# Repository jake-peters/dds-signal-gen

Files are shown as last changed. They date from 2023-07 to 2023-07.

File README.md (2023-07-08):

# DDS Signal Generator using AD9834

A signal generator designed around Analog Devices AD9834 DDS chip capable of outputting sinusoidal, triangle and square waves. Output filtering with a 9th order Elliptic filter or 7th order Linear Phase filter. PCB designed in KiCad 6.

V2 version includes update to correct orientation issue with latching relays.

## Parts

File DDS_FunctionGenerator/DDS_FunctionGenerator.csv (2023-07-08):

Source: | C:\Users\jakem\Documents\KiCad\6.0\projects\DDS_FunctionGen\DDS_FunctionGenerator\DDS_FunctionGenerator.kicad_sch
Date: | 1/28/2023 16:16
Tool: | Eeschema (6.0.6)
Generator: | D:\Programs\KiCad\6.0\bin\scripting\plugins/bom_csv_grouped_by_value.py
Component Count: | 137
Individual Components:
Item | Qty | Reference(s) | Value | LibPart | Footprint | Datasheet | Comp_Value | Part_Number
 |  | C1 | 10u | SMD_Passives:CAP_0805 | SMD_Passives_Reflow:SMD_0805 |  | 10u | GRM21BR61H106KE43L
 |  | C2 | 2u2 | SMD_Passives:CAP_0603 | SMD_Passives_Reflow:SMD_0603 |  | 2u2 | GRM188R6YA225KA12D
 |  | C3 | 10u | SMD_Passives:CAP_0805 | SMD_Passives_Reflow:SMD_0805 |  | 10u | GRM21BR61H106KE43L
 |  | C4 | 2u2 | SMD_Passives:CAP_0603 | SMD_Passives_Reflow:SMD_0603 |  | 2u2 | GRM188R6YA225KA12D
 |  | C5 | 2u2 | SMD_Passives:CAP_0603 | SMD_Passives_Reflow:SMD_0603 |  | 2u2 | GRM188R6YA225KA12D
 |  | C6 | 10u | SMD_Passives:CAP_0805 | SMD_Passives_Reflow:SMD_0805 |  | 10u | GRM21BR61H106KE43L
 |  | C7 | 2u2 | SMD_Passives:CAP_0603 | SMD_Passives_Reflow:SMD_0603 |  | 2u2 | GRM188R6YA225KA12D
 |  | C8 | 10u | SMD_Passives:CAP_0805 | SMD_Passives_Reflow:SMD_0805 |  | 10u | GRM21BR61H106KE43L
 |  | C9 | 2u2 | SMD_Passives:CAP_0603 | SMD_Passives_Reflow:SMD_0603 |  | 2u2 | GRM188R6YA225KA12D
 |  | C10 | 10u | SMD_Passives:CAP_0805 | SMD_Passives_Reflow:SMD_0805 |  | 10u | GRM21BR61H106KE43L
 |  | C11 | C11-DNI | SMD_Passives:CAP_0603 | SMD_Passives_Reflow:SMD_0603 |  | 10u | GRM21BR61H106KE43L
 |  | C12 | 100n | SMD_Passives:CAP_0603 | SMD_Passives_Reflow:SMD_0603 |  | 100n | 06035C104JAT4A
 |  | C13 | 5n6 | SMD_Passives:CAP_0603 | SMD_Passives_Reflow:SMD_0603 |  | 5n6 | 06035C562JAT2A
 |  | C14 | 2u2 | SMD_Passives:CAP_0603 | SMD_Passives_Reflow:SMD_0603 |  | 2u2 | GRM188R6YA225KA12D
 |  | C15 | C15-DNI | SMD_Passives:CAP_0603 | SMD_Passives_Reflow:SMD_0603 |  | DNI | GRM188R6YA225KA12D
 |  | C16 | 2u2 | SMD_Passives:CAP_0603 | SMD_Passives_Reflow:SMD_0603 |  | 2u2 | GRM188R6YA225KA12D
 |  | C17 | 8.6508E+11 | DDS_FunctionGenerator_Library:865080345010 | DDS_FunctionGenerator_Library:865080345010 |  | 150u | 8.6508E+11
 |  | C18 | 8.6508E+11 | DDS_FunctionGenerator_Library:865080345010 | DDS_FunctionGenerator_Library:865080345010 |  | 150u | 8.6508E+11
 |  | C19 | 2u2 | SMD_Passives:CAP_0603 | SMD_Passives_Reflow:SMD_0603 |  | 2u2 | GRM188R6YA225KA12D
 |  | C20 | 20p | SMD_Passives:CAP_0603 | SMD_Passives_Reflow:SMD_0603 |  | 20p | GCM1885C2A200FA16D
 |  | C21 | 82p | SMD_Passives:CAP_0603 | SMD_Passives_Reflow:SMD_0603 |  | 82p | GCM1885C2A820FA16D
 |  | C22 | 33p | SMD_Passives:CAP_0603 | SMD_Passives_Reflow:SMD_0603 |  | 33p | GRM1885C2A330FA01D
 |  | C23 | 82p | SMD_Passives:CAP_0603 | SMD_Passives_Reflow:SMD_0603 |  | 82p | GCM1885C2A820FA16D
 |  | C24 | 39p | SMD_Passives:CAP_0603 | SMD_Passives_Reflow:SMD_0603 |  | 39p | GRM1885C1H390FA01J
 |  | C25 | 160p | SMD_Passives:CAP_0603 | SMD_Passives_Reflow:SMD_0603 |  | 160p | GCM1885C2A161GA16J
 |  | C26 | 220p | SMD_Passives:CAP_0603 | SMD_Passives_Reflow:SMD_0603 |  | 220p | GCM1885C2A221FA16D
 |  | C27 | 240p | SMD_Passives:CAP_0603 | SMD_Passives_Reflow:SMD_0603 |  | 240p | GRM1885C1H241GA01J
 |  | C28 | 180p | SMD_Passives:CAP_0603 | SMD_Passives_Reflow:SMD_0603 |  | 180p | VJ0603A181FXACW1BC
 |  | C29 | 2u2 | SMD_Passives:CAP_0603 | SMD_Passives_Reflow:SMD_0603 |  | 2u2 | GRM188R6YA225KA12D
 |  | C30 | 62p | SMD_Passives:CAP_0603 | SMD_Passives_Reflow:SMD_0603 |  | 62p | GCM1885C2A620FA16D
 |  | C31 | 200p | SMD_Passives:CAP_0603 | SMD_Passives_Reflow:SMD_0603 |  | 200p | GCM1885C2A201FA16J
 |  | C32 | 270p | SMD_Passives:CAP_0603 | SMD_Passives_Reflow:SMD_0603 |  | 270p | GCM1885C2A271FA16D
 |  | C33 | 510p | SMD_Passives:CAP_0603 | SMD_Passives_Reflow:SMD_0603 |  | 510p | GRM1885C1H511GA01D
 |  | C34 | 10u | SMD_Passives:CAP_POL_0805 | SMD_Passives_Reflow:SMD_POL_0805 |  | 10u | TMCP1A106KTRF
 |  | C35 | 100n | SMD_Passives:CAP_0603 | SMD_Passives_Reflow:SMD_0603 |  | 100n | C0603C104J5RACTU
 |  | C36 | 100n | SMD_Passives:CAP_0603 | SMD_Passives_Reflow:SMD_0603 |  | 100n | C0603C104J5RACTU
 |  | C37 | 10u | SMD_Passives:CAP_POL_0805 | SMD_Passives_Reflow:SMD_POL_0805 |  | 10u | TMCP1A106KTRF
 |  | C38 | 500f | SMD_Passives:CAP_0402 | SMD_Passives_Reflow:SMD_0402 |  | 500f | GJM1555C1HR50WB01D
 |  | C39 | 10n | SMD_Passives:CAP_0603 | SMD_Passives_Reflow:SMD_0603 |  | 10n | C0603C103J5RACTU
 |  | C40 | 100n | SMD_Passives:CAP_0603 | SMD_Passives_Reflow:SMD_0603 |  | 100n | C0603C104J5RACTU
 |  | C41 | 100n | SMD_Passives:CAP_0603 | SMD_Passives_Reflow:SMD_0603 |  | 100n | C0603C104J5RACTU
 |  | C42 | 100n | SMD_Passives:CAP_0603 | SMD_Passives_Reflow:SMD_0603 |  | 100n | C0603C104J5RACTU
 |  | C43 | C43-DNI | SMD_Passives:CAP_0603 | SMD_Passives_Reflow:SMD_0603 |  | DNI | GRM1885C1H200GA01J
 |  | C44 | C44-DNI | SMD_Passives:CAP_0603 | SMD_Passives_Reflow:SMD_0603 |  | DNI | GRM1885C1H200GA01J
 |  | C45 | 100n | SMD_Passives:CAP_0603 | SMD_Passives_Reflow:SMD_0603 |  | 100n | C0603C104J5RACTU
 |  | C46 | C46-DNI | SMD_Passives:CAP_0402 | SMD_Passives_Reflow:SMD_0402 |  | DNI | GJM1555C1HR50WB01D
 |  | C47 | 2u2 | SMD_Passives:CAP_0603 | SMD_Passives_Reflow:SMD_0603 |  | 2u2 | GRM188R6YA225KA12D
 |  | C48 | 2u2 | SMD_Passives:CAP_0603 | SMD_Passives_Reflow:SMD_0603 |  | 2u2 | GRM188R6YA225KA12D
 |  | C49 | 2u2 | SMD_Passives:CAP_0603 | SMD_Passives_Reflow:SMD_0603 |  | 2u2 | GRM188R6YA225KA12D
 |  | C50 | 2u2 | SMD_Passives:CAP_0603 | SMD_Passives_Reflow:SMD_0603 |  | 2u2 | GRM188R6YA225KA12D
 |  | D1 | 1N4148W-E3-18 | DDS_FunctionGenerator_Library:1N4148W-E3-18 | DDS_FunctionGenerator_Library:SOD-123 |  |  | 1N4148W-E3-18
 |  | D2 | 1N4148W-E3-18 | DDS_FunctionGenerator_Library:1N4148W-E3-18 | DDS_FunctionGenerator_Library:SOD-123 |  |  | 1N4148W-E3-18
 |  | FB1 | 470R @ 100 MHz | SMD_Passives:BEAD_0603 | SMD_Passives_Reflow:SMD_0603 |  | 470R @ 100MHz | MMZ1608B471CTAH0
 |  | H1 | 0.152_IN_DIA | Mounting_Holes:0.152_IN_DIA | Mounting_Holes:0.152_IN_DIA-6-32 |  |  | 4817
 |  | H2 | 0.152_IN_DIA | Mounting_Holes:0.152_IN_DIA | Mounting_Holes:0.152_IN_DIA-6-32 |  |  | 4817
 |  | H3 | 0.152_IN_DIA | Mounting_Holes:0.152_IN_DIA | Mounting_Holes:0.152_IN_DIA-6-32 |  |  | 4817
 |  | H4 | 0.152_IN_DIA | Mounting_Holes:0.152_IN_DIA | Mounting_Holes:0.152_IN_DIA-6-32 |  |  | 4817
 |  | J1 | 6.91411E+11 | DDS_FunctionGenerator_Library:691411410002 | DDS_FunctionGenerator_Library:691411410002 |  |  | 6.91411E+11
 |  | J2 | SMA_CONN_TH | Connectors_Coax:SMA_CONN_TH | Connectors_Coax:SMA_CONN_TH |  |  | 901-144-8RFX
 |  | J3 | SMA_CONN_TH | Connectors_Coax:SMA_CONN_TH | Connectors_Coax:SMA_CONN_TH |  |  | 901-144-8RFX
 |  | J4 | HEADER_01X10 | Connectors_Header:HEADER_01X10 | Connector_PinSocket_2.54mm:PinSocket_1x10_P2.54mm_Vertical |  |  | 61301011821
 |  | J5 | SMA_CONN_TH | Connectors_Coax:SMA_CONN_TH | Connectors_Coax:SMA_CONN_TH |  |  | 901-144-8RFX
 |  | K1 | DS1E-SL-DC5V | DDS_FunctionGenerator_Library:DS1E-SL-DC5V | DDS_FunctionGenerator_Library:DS1E-SL-DC5V |  |  | DS1E-SL-DC5V
 |  | K2 | DS1E-SL-DC5V | :DS1E-SL-DC5V_1 | DDS_FunctionGenerator_Library:DS1E-SL-DC5V |  |  | DS1E-SL-DC5V
 |  | L1 | 33u | DDS_FunctionGenerator_Library:7447715330 | DDS_FunctionGenerator_Library:7447715330 |  | 33u | 7447715330
 |  | L2 | 330n | SMD_Passives:IND_1008 | SMD_Passives_Reflow:SMD_1008 |  | 330n | LQW2UASR33F00L
 |  | L3 | 390n | SMD_Passives:IND_1008 | SMD_Passives_Reflow:SMD_1008 |  | 390n | LQW2UASR39F00L
 |  | L4 | 620n | SMD_Passives:IND_1008 | SMD_Passives_Reflow:SMD_1008 |  | 620n | LQW2UASR62F0CL
 |  | L5 | 470n | SMD_Passives:IND_1008 | SMD_Passives_Reflow:SMD_1008 |  | 470n | LQW2UASR47F0CL
 |  | L6 | 390n | SMD_Passives:IND_1008 | SMD_Passives_Reflow:SMD_1008 |  | 390n | LQW2UASR39F00L
 |  | L7 | 580n | SMD_Passives:IND_0603 | SMD_Passives_Reflow:SMD_0603 |  | 580n | LQW18CAR58J00D
 |  | L8 | 820n | SMD_Passives:IND_1008 | SMD_Passives_Reflow:SMD_1008 |  | 820n | LQW2UASR82F00L
 |  | POT1 | PTN10-E200HB20 | DDS_FunctionGenerator_Library:PTN10-E200HB20 | DDS_FunctionGenerator_Library:PTN10-E200HB20 |  | 200k | PTN10-E200HB20
 |  | Q1 | BFR182W | DDS_FunctionGenerator_Library:BFR182W | DDS_FunctionGenerator_Library:SOT323_BFR182W |  |  | BFR182W
 |  | Q2 | BFR182W | DDS_FunctionGenerator_Library:BFR182W | DDS_FunctionGenerator_Library:SOT323_BFR182W |  |  | BFR182W
 |  | R1 | 100k | SMD_Passives:RES_0603 | SMD_Passives_Reflow:SMD_0603 |  | 100k | RT0603DRE10100KL
 |  | R2 | 100k | SMD_Passives:RES_0603 | SMD_Passives_Reflow:SMD_0603 |  | 100k | RT0603DRE10100KL
 |  | R3 | 28k7 | SMD_Passives:RES_0603 | SMD_Passives_Reflow:SMD_0603 |  | 28k7 | RT0603DRE0728K7L
 |  | R4 | 3M32 | SMD_Passives:RES_0603 | SMD_Passives_Reflow:SMD_0603 |  | 3M32 | RC0603FR-073M32L
 |  | R5 | 1M | SMD_Passives:RES_0603 | SMD_Passives_Reflow:SMD_0603 |  | 1M | RC0603FR-101ML
 |  | R6 | 53k6 | SMD_Passives:RES_0603 | SMD_Passives_Reflow:SMD_0603 |  | 53k6 | RT0603DRE0753K6L
 |  | R7 | 10k | SMD_Passives:RES_0603 | SMD_Passives_Reflow:SMD_0603 |  | 10k | RT0603FRE1310KL
 |  | R8 | 7k87 | SMD_Passives:RES_0603 | SMD_Passives_Reflow:SMD_0603 |  | 7k87 | RT0603DRE077K87L
 |  | R9 | 9k76 | SMD_Passives:RES_0603 | SMD_Passives_Reflow:SMD_0603 |  | 9k76 | RT0603DRE079K76L
 |  | R10 | 499R | SMD_Passives:RES_0603 | SMD_Passives_Reflow:SMD_0603 |  | 499R | RT0603DRD07499RL
 |  | R11 | 499R | SMD_Passives:RES_0603 | SMD_Passives_Reflow:SMD_0603 |  | 499R | RT0603DRD07499RL
 |  | R12 | 249R | SMD_Passives:RES_0603 | SMD_Passives_Reflow:SMD_0603 |  | 249R | RT0603BRD07249RL
 |  | R13 | 100R | SMD_Passives:RES_0603 | SMD_Passives_Reflow:SMD_0603 |  | 100R | CRCW0603100RFKEAHP
 |  | R14 | 100R | SMD_Passives:RES_0603 | SMD_Passives_Reflow:SMD_0603 |  | 100R | CRCW0603100RFKEAHP
 |  | R15 | 249R | SMD_Passives:RES_0603 | SMD_Passives_Reflow:SMD_0603 |  | 249R | RT0603BRD07249RL
 |  | R16 | 1k78 | SMD_Passives:RES_0603 | SMD_Passives_Reflow:SMD_0603 |  | 1k78 | RT0603DRD071K78L
 |  | R17 | 6k8 | SMD_Passives:RES_0603 | SMD_Passives_Reflow:SMD_0603 |  | 6k8 | RT0603DRE076K8L
 |  | R18 | 499R | SMD_Passives:RES_0603 | SMD_Passives_Reflow:SMD_0603 |  | 499R | RT0603DRE07499RL
 |  | R19 | 1k5 | SMD_Passives:RES_0603 | SMD_Passives_Reflow:SMD_0603 |  | 1k5 | RT0603DRE071K5L
 |  | R20 | 49R9 | SMD_Passives:RES_0603 | SMD_Passives_Reflow:SMD_0603 |  | 49R9 | RT0603DRE0749R9L
 |  | R21 | 200R | SMD_Passives:RES_0603 | SMD_Passives_Reflow:SMD_0603 |  | 200R | RT0603DRE07200RL
 |  | R22 | 200R | SMD_Passives:RES_0603 | SMD_Passives_Reflow:SMD_0603 |  | 200R | RT0603DRE07200RL
 |  | R23 | 0R | SMD_Passives:RES_0603 | SMD_Passives_Reflow:SMD_0603 |  | 0R | RC0603FR-070RL
 |  | R24 | 499R | SMD_Passives:RES_0603 | SMD_Passives_Reflow:SMD_0603 |  | 499R | RT0603DRE07499RL
 |  | R25 | 1k78 | SMD_Passives:RES_0603 | SMD_Passives_Reflow:SMD_0603 |  | 1k78 | RT0603DRD071K78L
 |  | R26 | 1k5 | SMD_Passives:RES_0603 | SMD_Passives_Reflow:SMD_0603 |  | 1k5 | RT0603DRE071K5L
 |  | TP1 | TestPoint_1.5mm_PAD | Connector:TestPoint | TestPoint:TestPoint_Pad_D1.5mm | ~ |  | N/A
 |  | TP2 | TestPoint_1.5mm_PAD | Connector:TestPoint | TestPoint:TestPoint_Pad_D1.5mm | ~ |  | N/A
 |  | TP3 | TestPoint_1.5mm_PAD | Connector:TestPoint | TestPoint:TestPoint_Pad_D1.5mm | ~ |  | N/A
 |  | TP4 | TestPoint_1.5mm_PAD | Connector:TestPoint | TestPoint:TestPoint_Pad_D1.5mm | ~ |  | N/A
 |  | TP5 | TestPoint_1.5mm_PAD | Connector:TestPoint | TestPoint:TestPoint_Pad_D1.5mm | ~ |  | N/A
 |  | TP6 | TestPoint_1.5mm_PAD | Connector:TestPoint | TestPoint:TestPoint_Pad_D1.5mm | ~ |  | N/A
 |  | TP7 | TestPoint_0.8mm_PAD | Connector:TestPoint | TestPoint:TestPoint_Pad_D0.8mm | ~ |  | N/A
 |  | TP8 | TestPoint_0.8mm_PAD | Connector:TestPoint | TestPoint:TestPoint_Pad_D0.8mm | ~ |  | N/A
 |  | TP9 | TestPoint_0.8mm_PAD | Connector:TestPoint | TestPoint:TestPoint_Pad_D0.8mm | ~ |  | N/A
 |  | TP11 | TestPoint_0.8mm_PAD | Connector:TestPoint | TestPoint:TestPoint_Pad_D0.8mm | ~ |  | N/A
 |  | TP12 | TestPoint_0.8mm_PAD | Connector:TestPoint | TestPoint:TestPoint_Pad_D0.8mm | ~ |  | N/A
 |  | TP13 | TestPoint_0.8mm_PAD | Connector:TestPoint | TestPoint:TestPoint_Pad_D0.8mm | ~ |  | N/A
 |  | TP14 | TestPoint_0.8mm_PAD | Connector:TestPoint | TestPoint:TestPoint_Pad_D0.8mm | ~ |  | N/A
 |  | TP15 | TestPoint_0.8mm_PAD | Connector:TestPoint | TestPoint:TestPoint_Pad_D0.8mm | ~ |  | N/A
 |  | TP16 | TestPoint_0.8mm_PAD | Connector:TestPoint | TestPoint:TestPoint_Pad_D0.8mm | ~ |  | N/A
 |  | TP17 | TestPoint_0.8mm_PAD | Connector:TestPoint | TestPoint:TestPoint_Pad_D0.8mm | ~ |  | N/A
 |  | TP18 | TestPoint_0.8mm_PAD | Connector:TestPoint | TestPoint:TestPoint_Pad_D0.8mm | ~ |  | N/A
 |  | TP20 | TestPoint_0.8mm_PAD | Connector:TestPoint | TestPoint:TestPoint_Pad_D0.8mm | ~ |  | N/A
 |  | TP21 | TestPoint_0.8mm_PAD | Connector:TestPoint | TestPoint:TestPoint_Pad_D0.8mm | ~ |  | N/A
 |  | TP22 | TestPoint_0.8mm_PAD | Connector:TestPoint | TestPoint:TestPoint_Pad_D0.8mm | ~ |  | N/A
 |  | TP23 | TestPoint_0.8mm_PAD | Connector:TestPoint | TestPoint:TestPoint_Pad_D0.8mm | ~ |  | N/A
 |  | TP24 | TestPoint_0.8mm_PAD | Connector:TestPoint | TestPoint:TestPoint_Pad_D0.8mm | ~ |  | N/A
 |  | TP25 | TestPoint_0.8mm_PAD | Connector:TestPoint | TestPoint:TestPoint_Pad_D0.8mm | ~ |  | N/A
 |  | TP26 | TestPoint_0.8mm_PAD | Connector:TestPoint | TestPoint:TestPoint_Pad_D0.8mm | ~ |  | N/A
 |  | TP27 | TestPoint_0.8mm_PAD | Connector:TestPoint | TestPoint:TestPoint_Pad_D0.8mm | ~ |  | N/A
 |  | TP28 | TestPoint_0.8mm_PAD | Connector:TestPoint | TestPoint:TestPoint_Pad_D0.8mm | ~ |  | N/A
 |  | TP29 | TestPoint_0.8mm_PAD | Connector:TestPoint | TestPoint:TestPoint_Pad_D0.8mm | ~ |  | N/A
 |  | U1 | ADP151AUJZ | DDS_FunctionGenerator_Library:ADP151AUJZ | DDS_FunctionGenerator_Library:TSOT_5Pin |  |  | ADP151AUJZ-3.3-R7
 |  | U2 | ADP7102 | DDS_FunctionGenerator_Library:ADP7102 | DDS_FunctionGenerator_Library:LFCSP_WD_8Pin |  |  | ADP7102ACPZ-5.0-R7
 |  | U3 | ADP7182AUJZ | DDS_FunctionGenerator_Library:ADP7182AUJZ | DDS_FunctionGenerator_Library:TSOT_5Pin |  |  | ADP7182AUJZ-5.0-R7
 |  | U4 | MAX17580ATC+ | DDS_FunctionGenerator_Library:MAX17580ATC+ | DDS_FunctionGenerator_Library:TDFN-EP_12Pin |  |  | MAX17580ATC+
 |  | U5 | MCP14A0602-E/SN | DDS_FunctionGenerator_Library:MCP14A0602-E{slash}SN | DDS_FunctionGenerator_Library:SOIC_8Pin |  |  | MCP14A0602-E/SN
 |  | U6 | LT1815IS5 | DDS_FunctionGenerator_Library:LT1815IS5 | DDS_FunctionGenerator_Library:TSOT-23_S5-Package |  |  | LT1815IS5
 |  | U7 | AD9834 | Interface:AD9834 | Package_SO:TSSOP-20_4.4x6.5mm_P0.65mm | https://www.analog.com/static/imported-files/data_sheets/AD9834.pdf |  | AD9834
 |  | U8 | LT1818IS8 | DDS_FunctionGenerator_Library:LT1818IS8 | DDS_FunctionGenerator_Library:S8_Package_LT1818 |  |  | LT1818IS8
 |  | X1 | ECS-TXO-2520MV-500-AY-TR | Oscillator:ECS-2520MV-xxx-xx | Oscillator:Oscillator_SMD_ECS_2520MV-xxx-xx-4Pin_2.5x2.0mm | https://www.ecsxtal.com/store/pdf/ECS-2520MV.pdf |  | ECS-TXO-2520MV-500-AY-TR
Collated Components:
Item | Qty | Reference(s) | Value | LibPart | Footprint | Datasheet | Comp_Value | Part_Number
1 | 5 | C1, C3, C6, C8, C10 | 10u | SMD_Passives:CAP_0805 | SMD_Passives_Reflow:SMD_0805 |  | 10u | GRM21BR61H106KE43L
2 | 13 | C2, C4, C5, C7, C9, C14, C16, C19, C29, C47, C48, C49, C50 | 2u2 | SMD_Passives:CAP_0603 | SMD_Passives_Reflow:SMD_0603 |  | 2u2 | GRM188R6YA225KA12D
3 | 1 | C11 | C11-DNI | SMD_Passives:CAP_0603 | SMD_Passives_Reflow:SMD_0603 |  | 10u | GRM21BR61H106KE43L
4 | 7 | C12, C35, C36, C40, C41, C42, C45 | 100n | SMD_Passives:CAP_0603 | SMD_Passives_Reflow:SMD_0603 |  | 100n | 06035C104JAT4A
5 | 1 | C13 | 5n6 | SMD_Passives:CAP_0603 | SMD_Passives_Reflow:SMD_0603 |  | 5n6 | 06035C562JAT2A
6 | 1 | C15 | C15-DNI | SMD_Passives:CAP_0603 | SMD_Passives_Reflow:SMD_0603 |  | DNI | GRM188R6YA225KA12D
7 | 2 | C17, C18 | 8.6508E+11 | DDS_FunctionGenerator_Library:865080345010 | DDS_FunctionGenerator_Library:865080345010 |  | 150u | 865080345010
8 | 1 | C20 | 20p | SMD_Passives:CAP_0603 | SMD_Passives_Reflow:SMD_0603 |  | 20p | GCM1885C2A200FA16D
9 | 2 | C21, C23 | 82p | SMD_Passives:CAP_0603 | SMD_Passives_Reflow:SMD_0603 |  | 82p | GCM1885C2A820FA16D
10 | 1 | C22 | 33p | SMD_Passives:CAP_0603 | SMD_Passives_Reflow:SMD_0603 |  | 33p | GRM1885C2A330FA01D
11 | 1 | C24 | 39p | SMD_Passives:CAP_0603 | SMD_Passives_Reflow:SMD_0603 |  | 39p | GRM1885C1H390FA01J
12 | 1 | C25 | 160p | SMD_Passives:CAP_0603 | SMD_Passives_Reflow:SMD_0603 |  | 160p | GCM1885C2A161GA16J
13 | 1 | C26 | 220p | SMD_Passives:CAP_0603 | SMD_Passives_Reflow:SMD_0603 |  | 220p | GCM1885C2A221FA16D
14 | 1 | C27 | 240p | SMD_Passives:CAP_0603 | SMD_Passives_Reflow:SMD_0603 |  | 240p | GRM1885C1H241GA01J
15 | 1 | C28 | 180p | SMD_Passives:CAP_0603 | SMD_Passives_Reflow:SMD_0603 |  | 180p | VJ0603A181FXACW1BC
16 | 1 | C30 | 62p | SMD_Passives:CAP_0603 | SMD_Passives_Reflow:SMD_0603 |  | 62p | GCM1885C2A620FA16D
17 | 1 | C31 | 200p | SMD_Passives:CAP_0603 | SMD_Passives_Reflow:SMD_0603 |  | 200p | GCM1885C2A201FA16J
18 | 1 | C32 | 270p | SMD_Passives:CAP_0603 | SMD_Passives_Reflow:SMD_0603 |  | 270p | GCM1885C2A271FA16D
19 | 1 | C33 | 510p | SMD_Passives:CAP_0603 | SMD_Passives_Reflow:SMD_0603 |  | 510p | GRM1885C1H511GA01D
20 | 2 | C34, C37 | 10u | SMD_Passives:CAP_POL_0805 | SMD_Passives_Reflow:SMD_POL_0805 |  | 10u | TMCP1A106KTRF
21 | 1 | C38 | 500f | SMD_Passives:CAP_0402 | SMD_Passives_Reflow:SMD_0402 |  | 500f | GJM1555C1HR50WB01D
22 | 1 | C39 | 10n | SMD_Passives:CAP_0603 | SMD_Passives_Reflow:SMD_0603 |  | 10n | C0603C103J5RACTU
23 | 1 | C43 | C43-DNI | SMD_Passives:CAP_0603 | SMD_Passives_Reflow:SMD_0603 |  | DNI | GRM1885C1H200GA01J
24 | 1 | C44 | C44-DNI | SMD_Passives:CAP_0603 | SMD_Passives_Reflow:SMD_0603 |  | DNI | GRM1885C1H200GA01J
25 | 1 | C46 | C46-DNI | SMD_Passives:CAP_0402 | SMD_Passives_Reflow:SMD_0402 |  | DNI | GJM1555C1HR50WB01D
26 | 2 | D1, D2 | 1N4148W-E3-18 | DDS_FunctionGenerator_Library:1N4148W-E3-18 | DDS_FunctionGenerator_Library:SOD-123 |  |  | 1N4148W-E3-18
27 | 1 | FB1 | 470R @ 100 MHz | SMD_Passives:BEAD_0603 | SMD_Passives_Reflow:SMD_0603 |  | 470R @ 100MHz | MMZ1608B471CTAH0
28 | 4 | H1, H2, H3, H4 | 0.152_IN_DIA | Mounting_Holes:0.152_IN_DIA | Mounting_Holes:0.152_IN_DIA-6-32 |  |  | 4817
29 | 1 | J1 | 6.91411E+11 | DDS_FunctionGenerator_Library:691411410002 | DDS_FunctionGenerator_Library:691411410002 |  |  | 691411410002
30 | 3 | J2, J3, J5 | SMA_CONN_TH | Connectors_Coax:SMA_CONN_TH | Connectors_Coax:SMA_CONN_TH |  |  | 901-144-8RFX
31 | 1 | J4 | HEADER_01X10 | Connectors_Header:HEADER_01X10 | Connector_PinSocket_2.54mm:PinSocket_1x10_P2.54mm_Vertical |  |  | 61301011821
32 | 1 | K1 | DS1E-SL-DC5V | DDS_FunctionGenerator_Library:DS1E-SL-DC5V | DDS_FunctionGenerator_Library:DS1E-SL-DC5V |  |  | DS1E-SL-DC5V
33 | 1 | K2 | DS1E-SL-DC5V | :DS1E-SL-DC5V_1 | DDS_FunctionGenerator_Library:DS1E-SL-DC5V |  |  | DS1E-SL-DC5V
34 | 1 | L1 | 33u | DDS_FunctionGenerator_Library:7447715330 | DDS_FunctionGenerator_Library:7447715330 |  | 33u | 7447715330
35 | 1 | L2 | 330n | SMD_Passives:IND_1008 | SMD_Passives_Reflow:SMD_1008 |  | 330n | LQW2UASR33F00L
36 | 2 | L3, L6 | 390n | SMD_Passives:IND_1008 | SMD_Passives_Reflow:SMD_1008 |  | 390n | LQW2UASR39F00L
37 | 1 | L4 | 620n | SMD_Passives:IND_1008 | SMD_Passives_Reflow:SMD_1008 |  | 620n | LQW2UASR62F0CL
38 | 1 | L5 | 470n | SMD_Passives:IND_1008 | SMD_Passives_Reflow:SMD_1008 |  | 470n | LQW2UASR47F0CL
39 | 1 | L7 | 580n | SMD_Passives:IND_0603 | SMD_Passives_Reflow:SMD_0603 |  | 580n | LQW18CAR58J00D
40 | 1 | L8 | 820n | SMD_Passives:IND_1008 | SMD_Passives_Reflow:SMD_1008 |  | 820n | LQW2UASR82F00L
41 | 1 | POT1 | PTN10-E200HB20 | DDS_FunctionGenerator_Library:PTN10-E200HB20 | DDS_FunctionGenerator_Library:PTN10-E200HB20 |  | 200k | PTN10-E200HB20
42 | 2 | Q1, Q2 | BFR182W | DDS_FunctionGenerator_Library:BFR182W | DDS_FunctionGenerator_Library:SOT323_BFR182W |  |  | BFR182W
43 | 2 | R1, R2 | 100k | SMD_Passives:RES_0603 | SMD_Passives_Reflow:SMD_0603 |  | 100k | RT0603DRE10100KL
44 | 1 | R3 | 28k7 | SMD_Passives:RES_0603 | SMD_Passives_Reflow:SMD_0603 |  | 28k7 | RT0603DRE0728K7L
45 | 1 | R4 | 3M32 | SMD_Passives:RES_0603 | SMD_Passives_Reflow:SMD_0603 |  | 3M32 | RC0603FR-073M32L
46 | 1 | R5 | 1M | SMD_Passives:RES_0603 | SMD_Passives_Reflow:SMD_0603 |  | 1M | RC0603FR-101ML
47 | 1 | R6 | 53k6 | SMD_Passives:RES_0603 | SMD_Passives_Reflow:SMD_0603 |  | 53k6 | RT0603DRE0753K6L
48 | 1 | R7 | 10k | SMD_Passives:RES_0603 | SMD_Passives_Reflow:SMD_0603 |  | 10k | RT0603FRE1310KL
49 | 1 | R8 | 7k87 | SMD_Passives:RES_0603 | SMD_Passives_Reflow:SMD_0603 |  | 7k87 | RT0603DRE077K87L
50 | 1 | R9 | 9k76 | SMD_Passives:RES_0603 | SMD_Passives_Reflow:SMD_0603 |  | 9k76 | RT0603DRE079K76L
51 | 4 | R10, R11, R18, R24 | 499R | SMD_Passives:RES_0603 | SMD_Passives_Reflow:SMD_0603 |  | 499R | RT0603DRD07499RL
52 | 2 | R12, R15 | 249R | SMD_Passives:RES_0603 | SMD_Passives_Reflow:SMD_0603 |  | 249R | RT0603BRD07249RL
53 | 2 | R13, R14 | 100R | SMD_Passives:RES_0603 | SMD_Passives_Reflow:SMD_0603 |  | 100R | CRCW0603100RFKEAHP
54 | 2 | R16, R25 | 1k78 | SMD_Passives:RES_0603 | SMD_Passives_Reflow:SMD_0603 |  | 1k78 | RT0603DRD071K78L
55 | 1 | R17 | 6k8 | SMD_Passives:RES_0603 | SMD_Passives_Reflow:SMD_0603 |  | 6k8 | RT0603DRE076K8L
56 | 2 | R19, R26 | 1k5 | SMD_Passives:RES_0603 | SMD_Passives_Reflow:SMD_0603 |  | 1k5 | RT0603DRE071K5L
57 | 1 | R20 | 49R9 | SMD_Passives:RES_0603 | SMD_Passives_Reflow:SMD_0603 |  | 49R9 | RT0603DRE0749R9L
58 | 2 | R21, R22 | 200R | SMD_Passives:RES_0603 | SMD_Passives_Reflow:SMD_0603 |  | 200R | RT0603DRE07200RL
59 | 1 | R23 | 0R | SMD_Passives:RES_0603 | SMD_Passives_Reflow:SMD_0603 |  | 0R | RC0603FR-070RL
60 | 6 | TP1, TP2, TP3, TP4, TP5, TP6 | TestPoint_1.5mm_PAD | Connector:TestPoint | TestPoint:TestPoint_Pad_D1.5mm | ~ |  | N/A
61 | 21 | TP7, TP8, TP9, TP11, TP12, TP13, TP14, TP15, TP16, TP17, TP18, TP20, TP21, TP22, TP23, TP24, TP25, TP26, TP27, TP28, TP29 | TestPoint_0.8mm_PAD | Connector:TestPoint | TestPoint:TestPoint_Pad_D0.8mm | ~ |  | N/A
62 | 1 | U1 | ADP151AUJZ | DDS_FunctionGenerator_Library:ADP151AUJZ | DDS_FunctionGenerator_Library:TSOT_5Pin |  |  | ADP151AUJZ-3.3-R7
63 | 1 | U2 | ADP7102 | DDS_FunctionGenerator_Library:ADP7102 | DDS_FunctionGenerator_Library:LFCSP_WD_8Pin |  |  | ADP7102ACPZ-5.0-R7
64 | 1 | U3 | ADP7182AUJZ | DDS_FunctionGenerator_Library:ADP7182AUJZ | DDS_FunctionGenerator_Library:TSOT_5Pin |  |  | ADP7182AUJZ-5.0-R7
65 | 1 | U4 | MAX17580ATC+ | DDS_FunctionGenerator_Library:MAX17580ATC+ | DDS_FunctionGenerator_Library:TDFN-EP_12Pin |  |  | MAX17580ATC+
66 | 1 | U5 | MCP14A0602-E/SN | DDS_FunctionGenerator_Library:MCP14A0602-E{slash}SN | DDS_FunctionGenerator_Library:SOIC_8Pin |  |  | MCP14A0602-E/SN
67 | 1 | U6 | LT1815IS5 | DDS_FunctionGenerator_Library:LT1815IS5 | DDS_FunctionGenerator_Library:TSOT-23_S5-Package |  |  | LT1815IS5
68 | 1 | U7 | AD9834 | Interface:AD9834 | Package_SO:TSSOP-20_4.4x6.5mm_P0.65mm | https://www.analog.com/static/imported-files/data_sheets/AD9834.pdf |  | AD9834
69 | 1 | U8 | LT1818IS8 | DDS_FunctionGenerator_Library:LT1818IS8 | DDS_FunctionGenerator_Library:S8_Package_LT1818 |  |  | LT1818IS8
70 | 1 | X1 | ECS-TXO-2520MV-500-AY-TR | Oscillator:ECS-2520MV-xxx-xx | Oscillator:Oscillator_SMD_ECS_2520MV-xxx-xx-4Pin_2.5x2.0mm | https://www.ecsxtal.com/store/pdf/ECS-2520MV.pdf |  | ECS-TXO-2520MV-500-AY-TR

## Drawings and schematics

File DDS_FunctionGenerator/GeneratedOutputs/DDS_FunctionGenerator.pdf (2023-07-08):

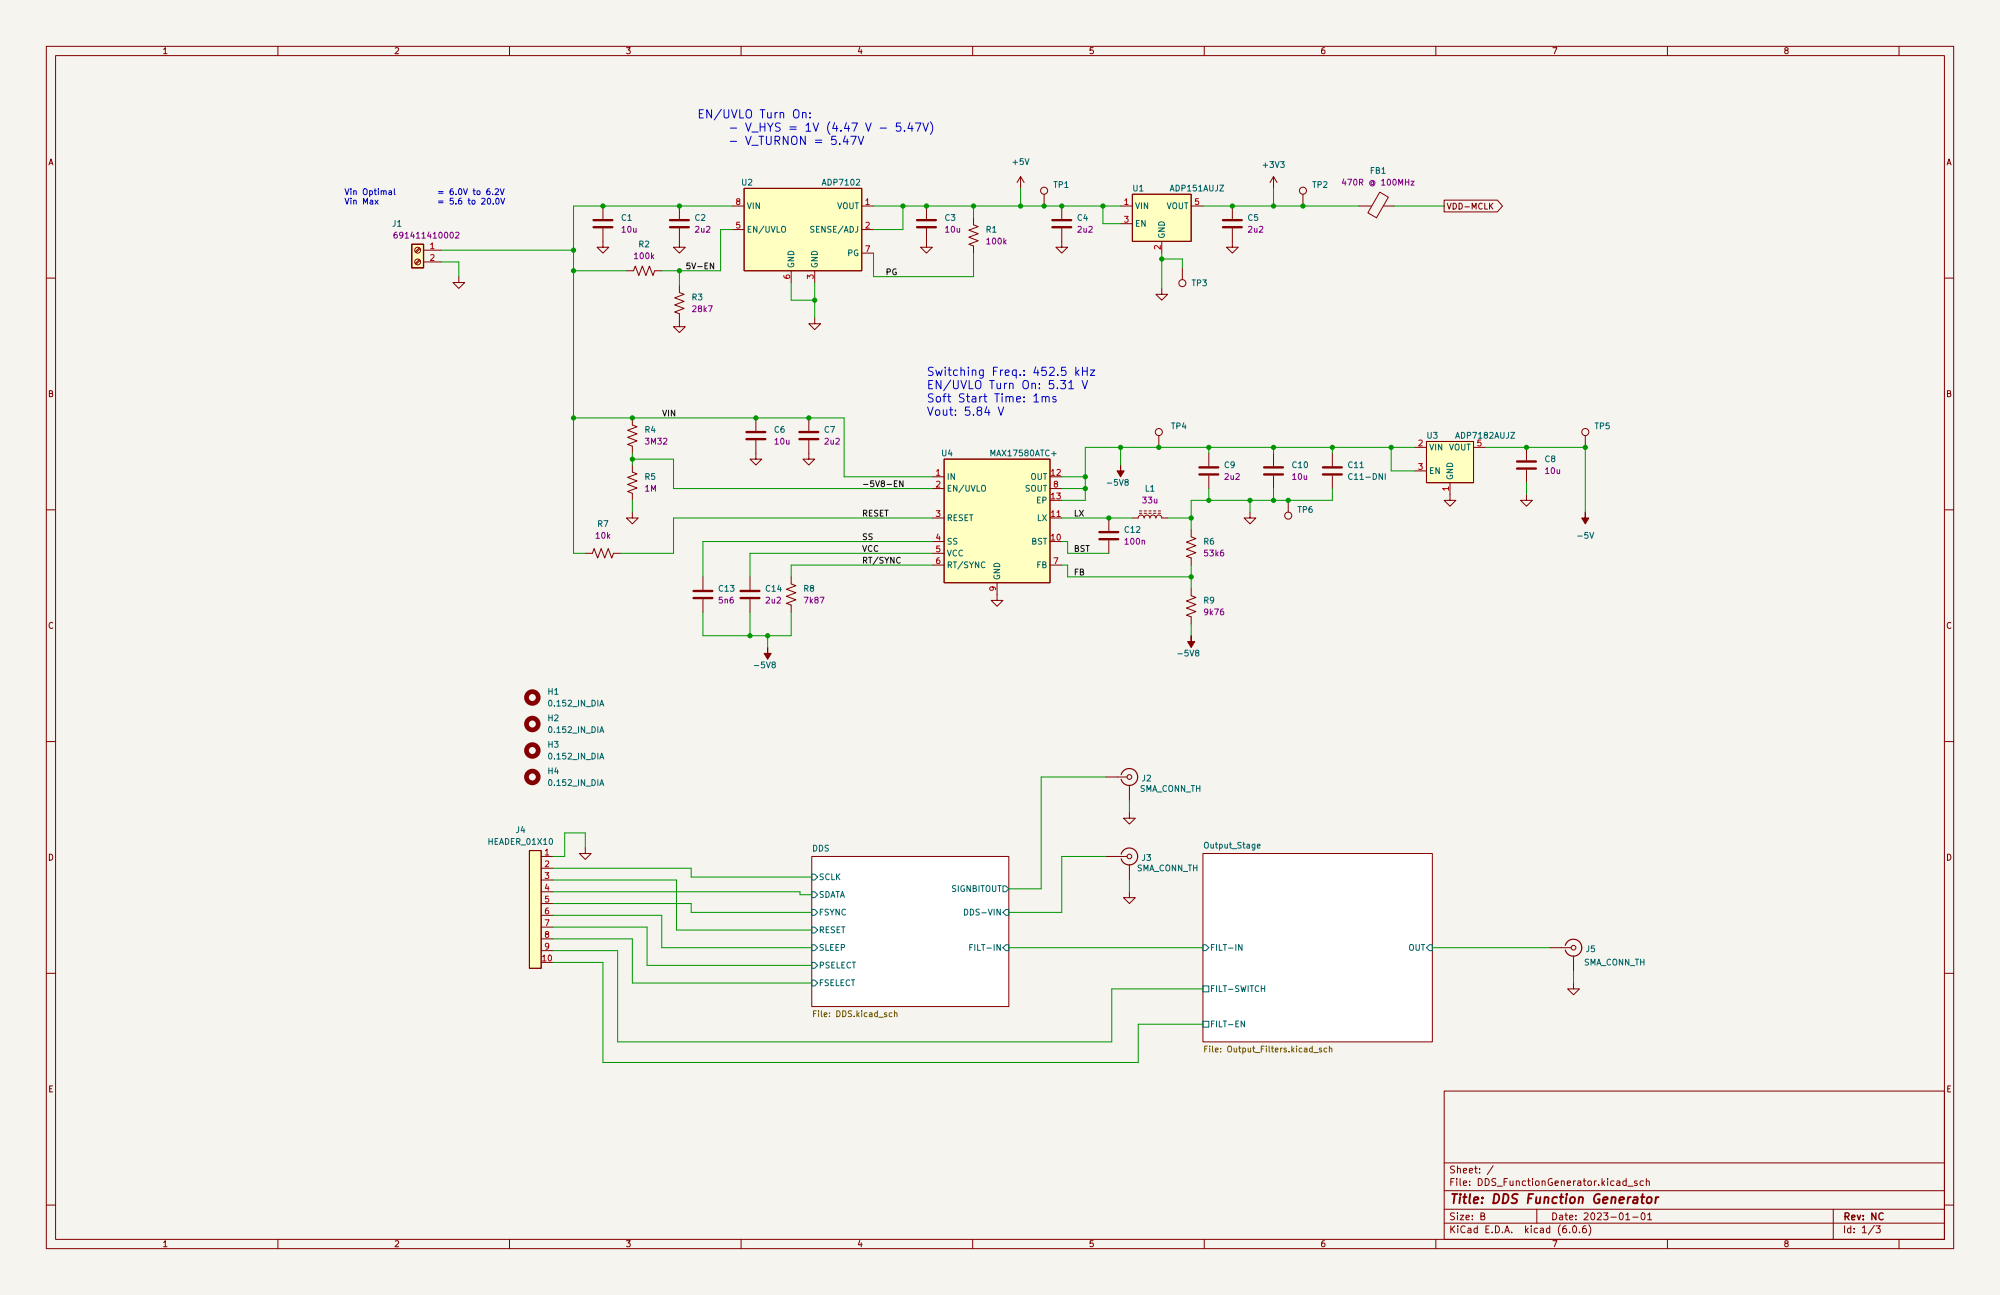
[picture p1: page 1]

Switching Freq.: 452.5 kHz
EN/UVLO Turn On: 5.31 V
Soft Start Time: 1ms
Vout: 5.84 V

BST RESET RT/SYNC

File: Output_Filters.kicad_sch SIGNBITOUT DDS-VIN

Id: 1/3 Title: DDS Function Generator

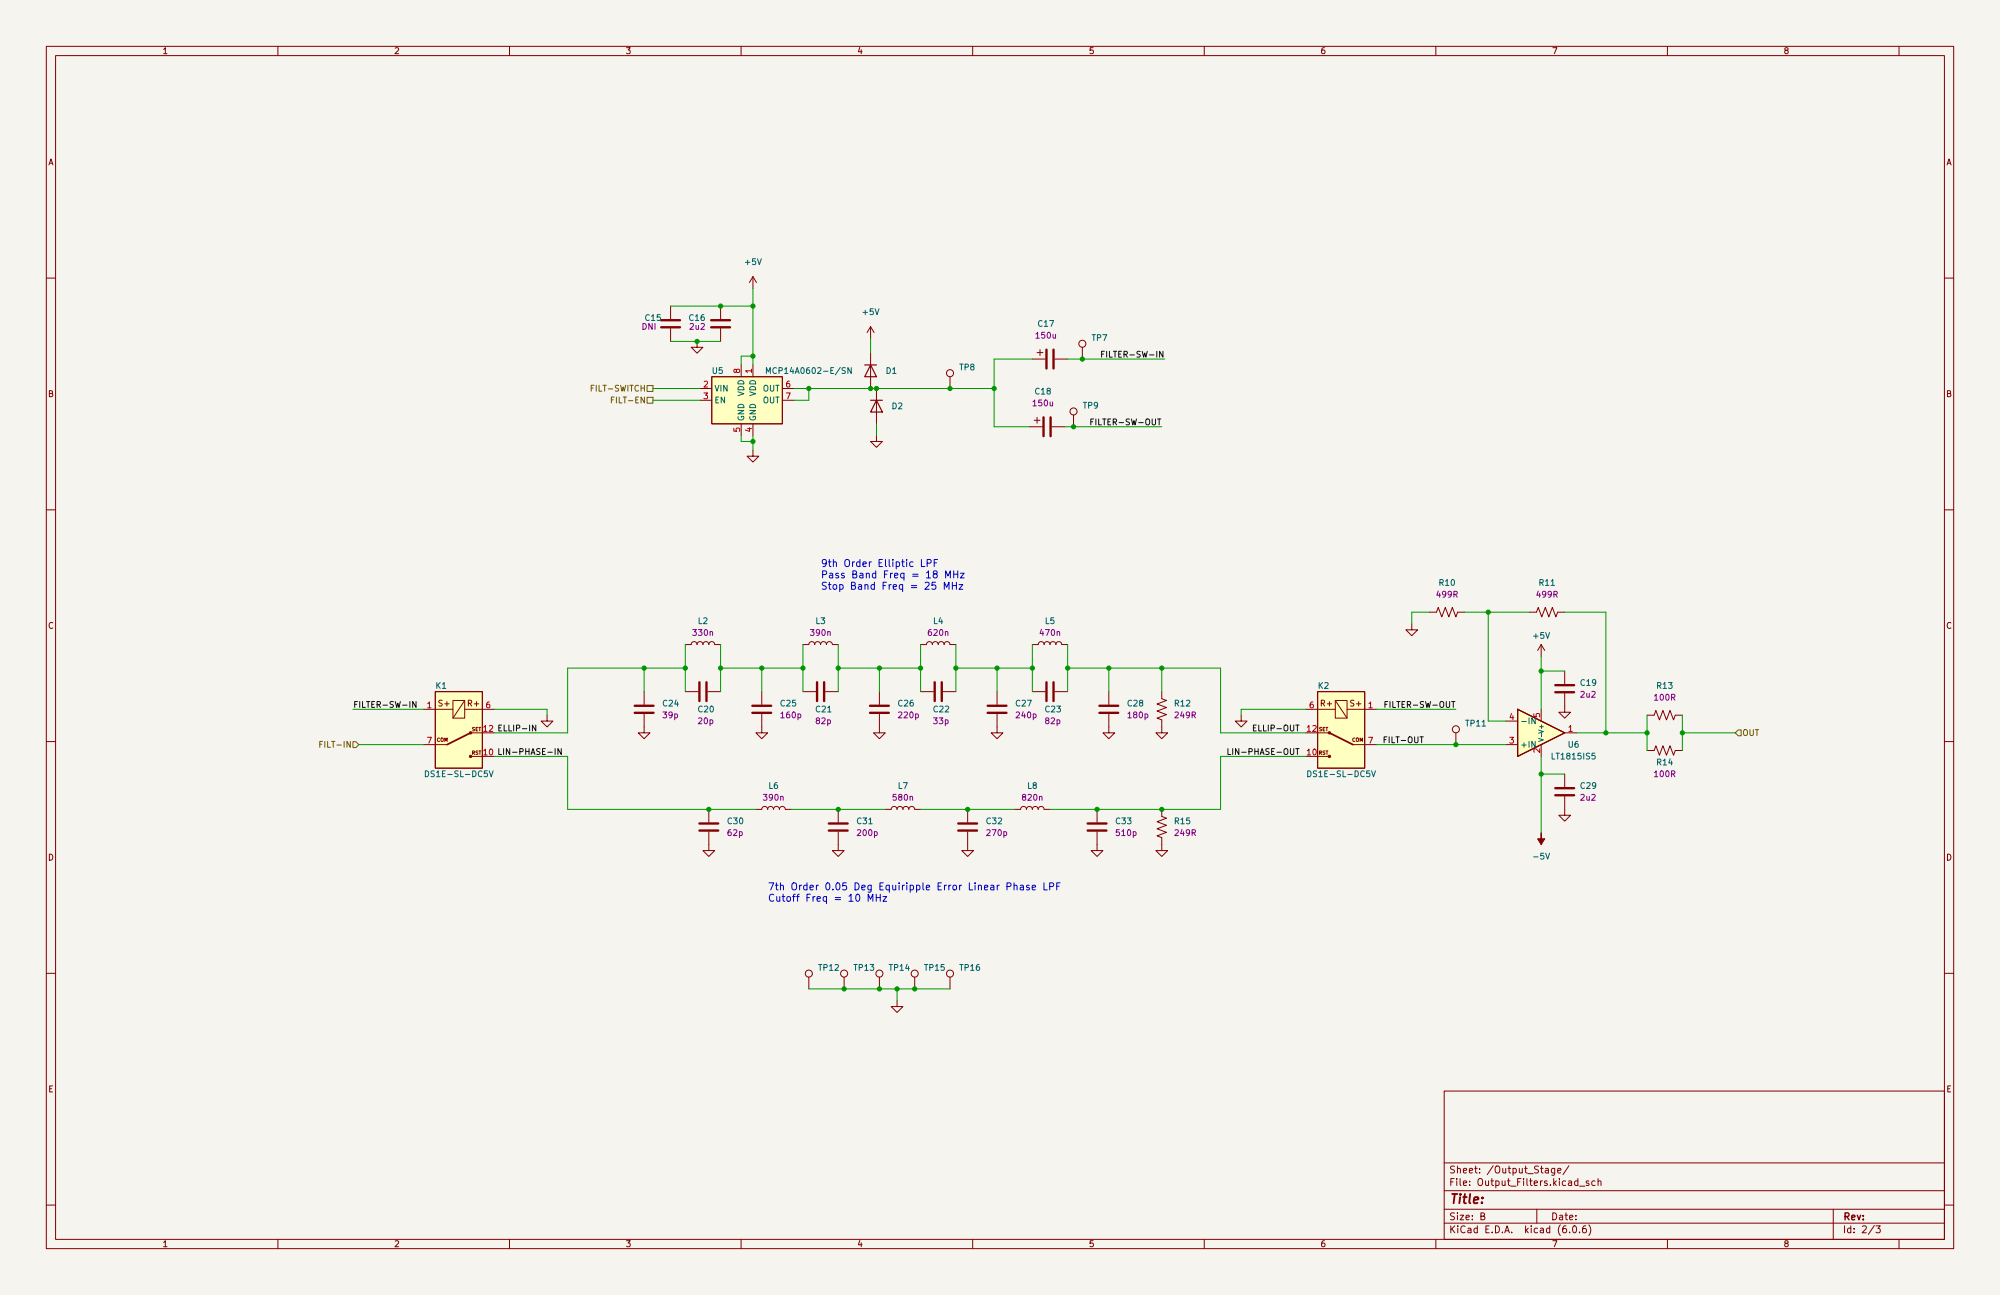
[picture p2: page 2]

5 OUT 6 OUT VDD 7 U5 8MCP14A0602-E/SN

FILTER-SW-OUT ELLIP-OUT 9th Order Elliptic LPF
Pass Band Freq = 18 MHz
Stop Band Freq = 25 MHz

7th Order 0.05 Deg Equiripple Error Linear Phase LPF
Cutoff Freq = 10 MHz

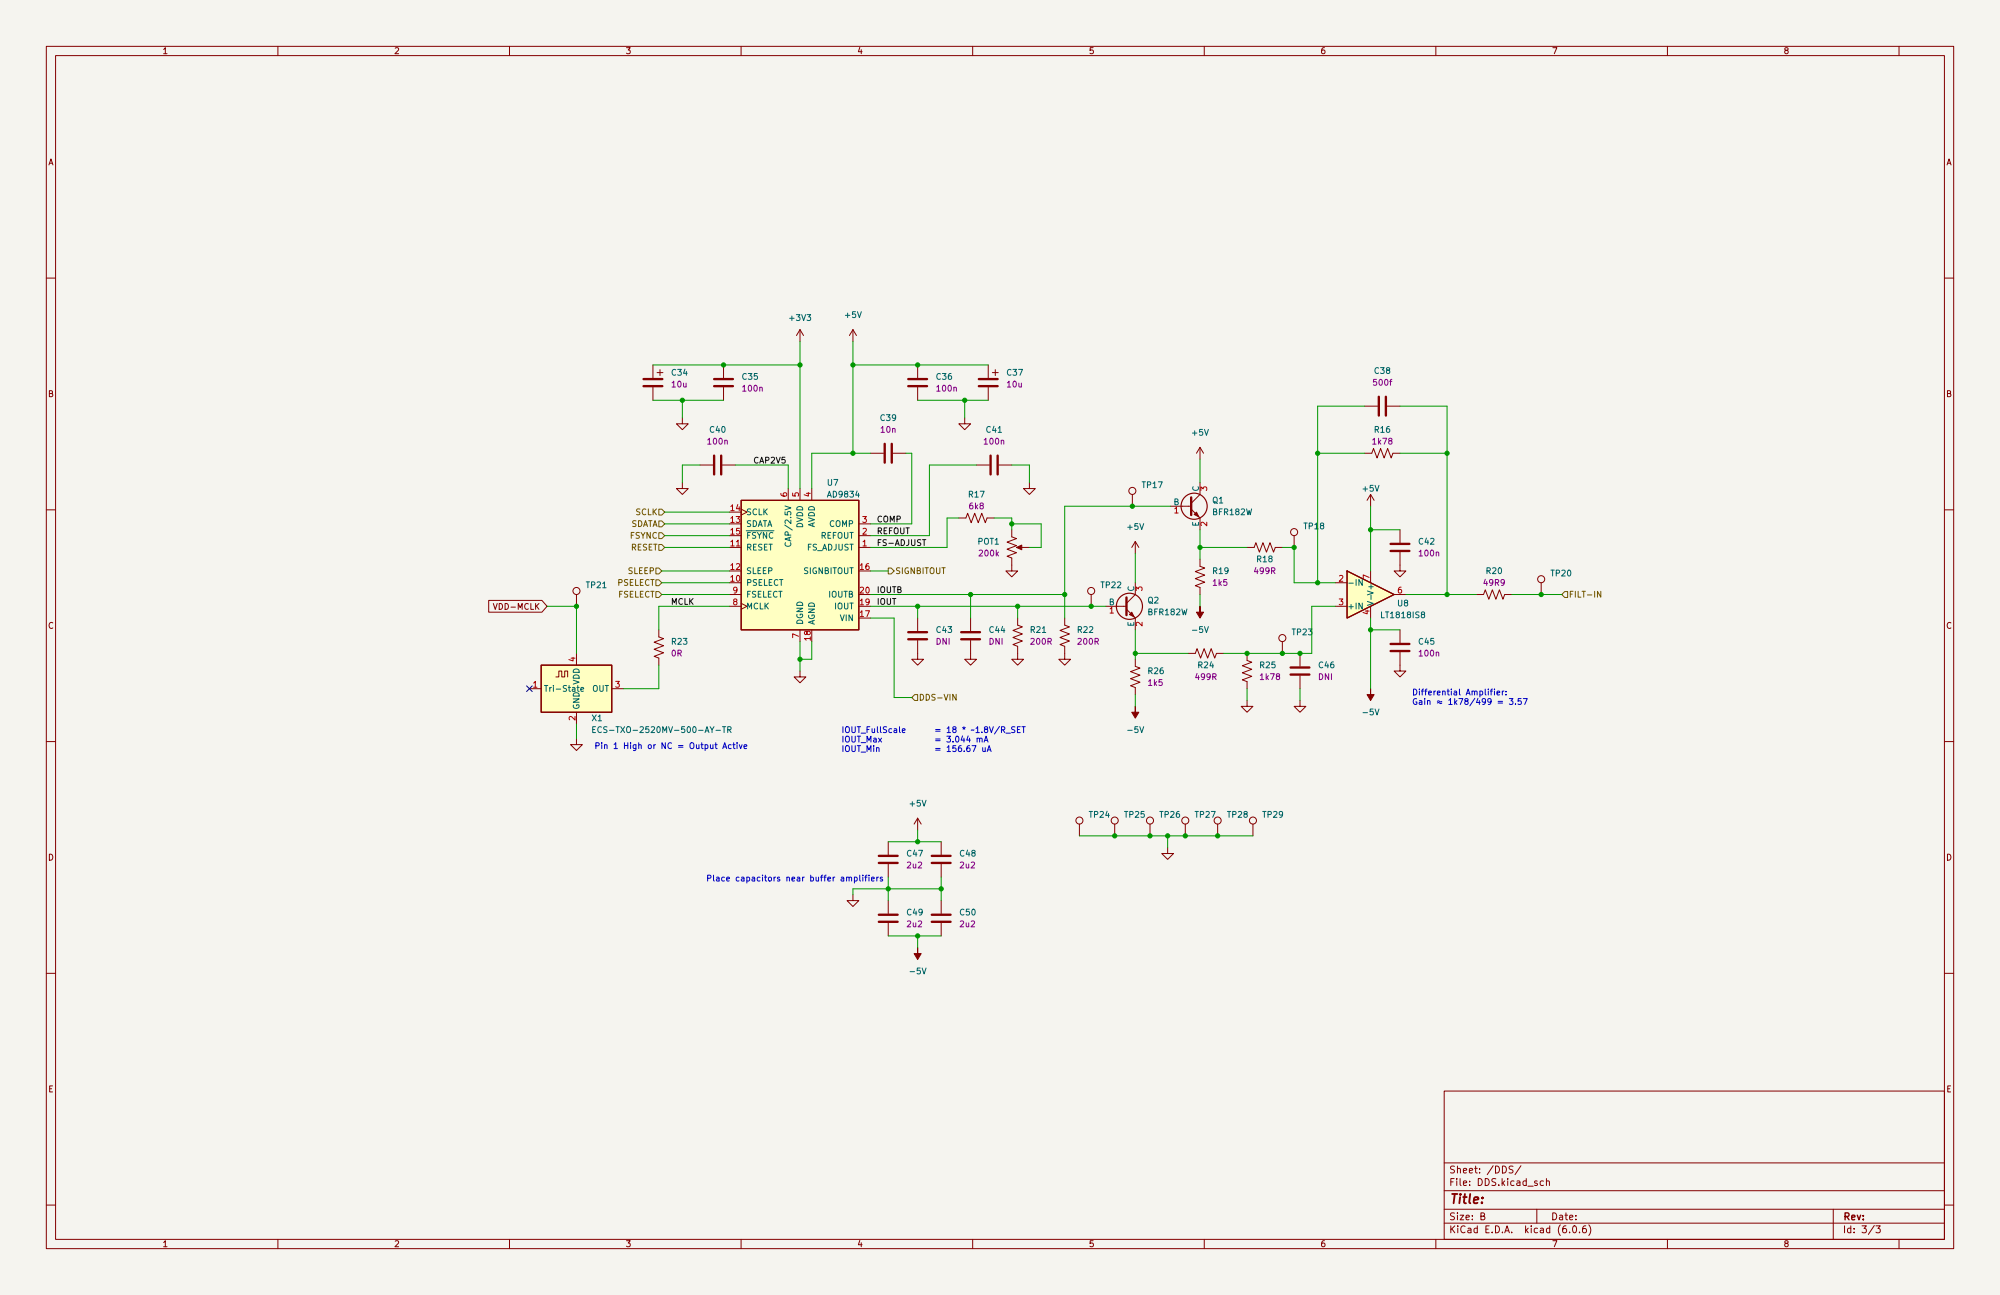
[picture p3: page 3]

IOUT Place capacitors near buffer amplifiers

4 X1 ECS-TXO-2520MV-500-AY-TR

Pin 1 High or NC = Output Active

File: DDS.kicad_sch Sheet: /DDS/

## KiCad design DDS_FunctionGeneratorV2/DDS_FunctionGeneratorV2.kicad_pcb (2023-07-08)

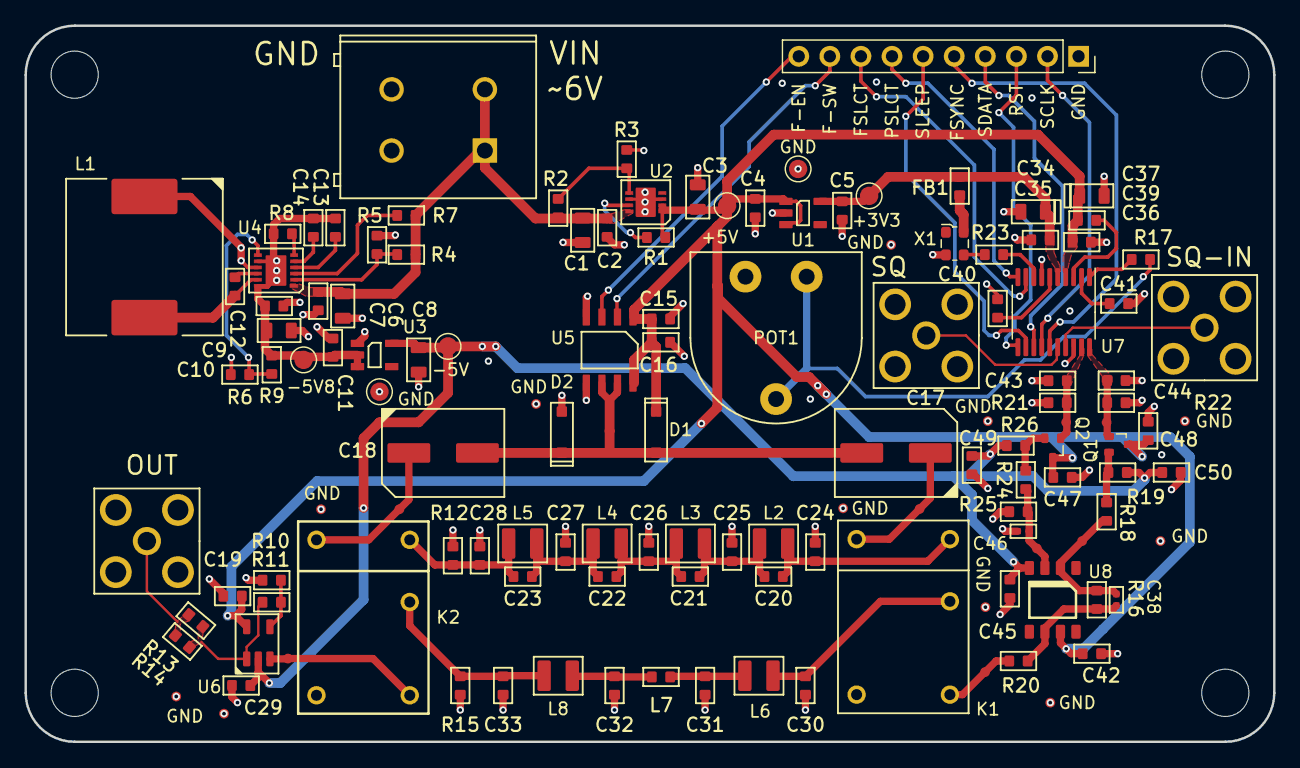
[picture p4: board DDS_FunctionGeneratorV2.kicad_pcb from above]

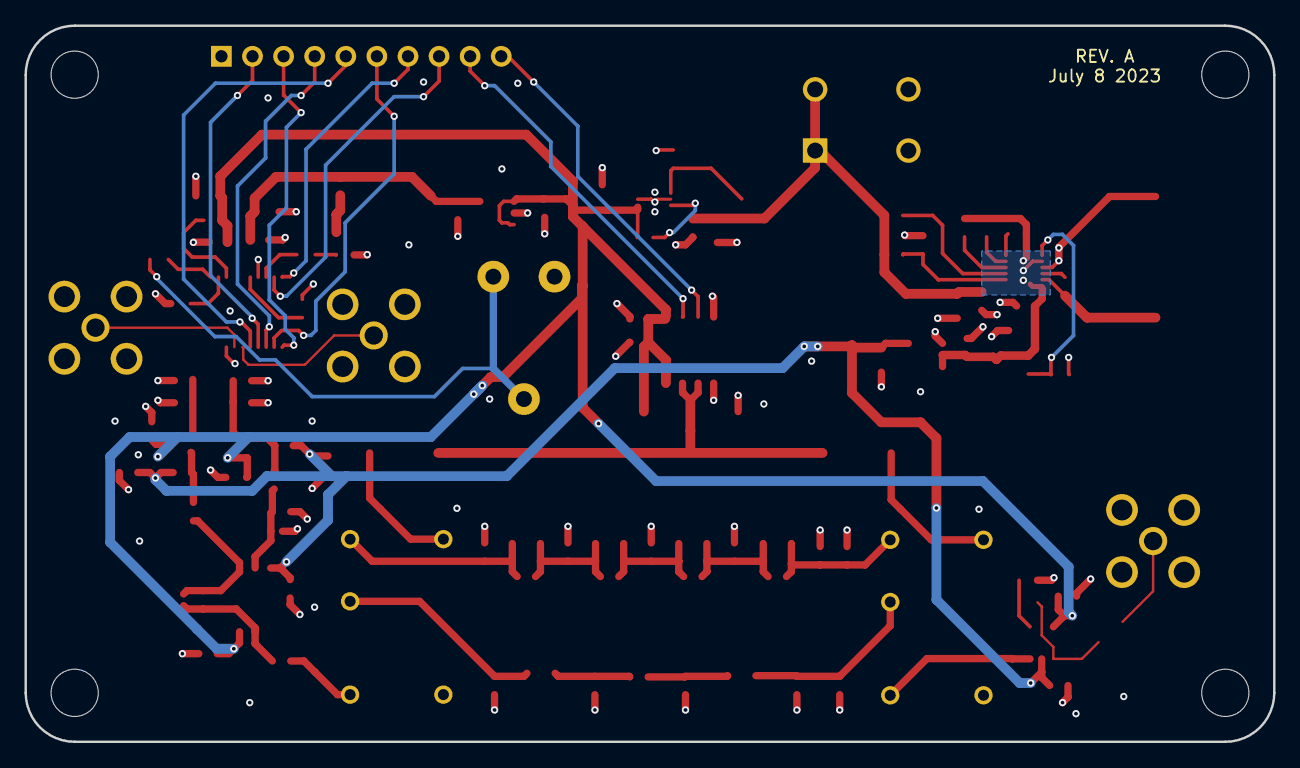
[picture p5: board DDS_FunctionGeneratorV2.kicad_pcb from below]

Board: 4 copper layers, 102.0 x 58.5 mm, 137 parts (2 on the bottom side), 59 nets.

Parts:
C1, C3, C6, C8, C10: CAP_0805; SMD_0805
C2, C4, C5, C7, C9, C11, C12, C13, C14, C15, C16, C19, C20, C21, C22, C23, C24, C25, C26, C27, C28, C29, C30, C31, C32, C33, C35, C36, C39, C40, C41, C42, C43, C44, C45, C47, C48, C49, C50: CAP_0603; SMD_0603
C17, C18: 865080345010
C34, C37: CAP_POL_0805; SMD_POL_0805
C38, C46: CAP_0402; SMD_0402
D1, D2: 1N4148W-E3-18; SOD-123
FB1: BEAD_0603; SMD_0603
H1, H2, H3, H4: 0.152_IN_DIA; 0.152_IN_DIA-6-32
J1: 691411410002
J2, J3, J5: SMA_CONN_TH
J4: HEADER_01X10; PinSocket_1x10_P2.54mm_Vertical
K1, K2: DS1E-SL-DC5V
L1: 7447715330
L2, L3, L4, L5, L6, L8: IND_1008; SMD_1008
L7: IND_0603; SMD_0603
POT1: PTN10-E200HB20
Q1, Q2: BFR182W; SOT323_BFR182W
R1, R2, R3, R4, R5, R6, R7, R8, R9, R10, R11, R12, R13, R14, R15, R16, R17, R18, R19, R20, R21, R22, R23, R24, R25, R26: RES_0603; SMD_0603
TP1, TP2, TP3, TP4, TP5, TP6: TestPoint_2.0mm_PAD; TestPoint_Pad_D1.5mm
TP7, TP8, TP9, TP11, TP12, TP13, TP14, TP15, TP16, TP17, TP18, TP20, TP21, TP22, TP23, TP24, TP25, TP26, TP27, TP28, TP29: TestPoint_2.0mm_PAD; TestPoint_Pad_D0.8mm
U1: ADP151AUJZ; TSOT_5Pin
U2: ADP7102; LFCSP_WD_8Pin
U3: ADP7182AUJZ; TSOT_5Pin
U4: MAX17580ATC+; TDFN-EP_12Pin
U5: MCP14A0602-E/SN; SOIC_8Pin
U6: LT1815IS5; TSOT-23_S5-Package
U7: AD9834; TSSOP-20_4.4x6.5mm_P0.65mm
U8: LT1818IS8; S8_Package_LT1818
X1: ECS-TXO-2520MV-500-AY-TR; Oscillator_SMD_ECS_2520MV-xxx-xx-4Pin_2.5x2.0mm

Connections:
+3V3: C5.1, C34.1, C35.2, FB1.1, TP2.1, U1.5 (VOUT), U7.5 (DVDD)
+5V: C3.1, C4.1, C15.1, C16.2, C19.1, C36.2, C37.1, C39.2, C42.2, C47.1, C48.1, D1.1 (K), Q1.3 (C), Q2.3 (C), R1.1, TP1.1, U1.1 (VIN), U1.3 (EN), U2.1 (VOUT), U2.2 (SENSE/ADJ), U5.1 (VDD), U5.8 (VDD), U6.5 (V+), U7.4 (AVDD), U8.7 (V+)
-5V: C8.1, C29.1, C45.2, C49.2, C50.2, R19.2, R26.2, TP5.1, U3.5 (VOUT), U6.2 (V-), U8.4 (V-)
-5V8: C9.1, C10.1, C11.1, C13.2, C14.2, R8.2, R9.2, TP4.1, U3.2 (VIN), U3.3 (EN), U4.8 (SOUT), U4.12 (OUT), U4.13 (EP)
/5V-EN: R2.2, R3.1, U2.5 (EN/UVLO)
/-5V8-EN: R4.1, R5.2, U4.2 (EN/UVLO)
/BST: C12.2, U4.10 (BST)
/DDS/CAP2V5: C40.2, U7.6 (CAP/2.5V)
/DDS/COMP: C39.1, U7.3 (COMP)
/DDS/DDS-VIN: J3.1 (In), U7.17 (VIN)
/DDS/FILT-IN: K1.7, R20.1, TP20.1
/DDS/FS-ADJUST: R17.2, U7.1 (FS_ADJUST)
/DDS/FSELECT: J4.8 (PIN), U7.9 (FSELECT)
/DDS/FSYNC: J4.5 (PIN), U7.15 (~FSYNC)
/DDS/IOUT: C43.1, Q2.1 (B), R21.1, TP22.1, U7.19 (IOUT)
/DDS/IOUTB: C44.1, Q1.1 (B), R22.1, TP17.1, U7.20 (IOUTB)
/DDS/MCLK: R23.1, U7.8 (MCLK)
/DDS/PSELECT: J4.7 (PIN), U7.10 (PSELECT)
/DDS/REFOUT: C41.1, U7.2 (REFOUT)
/DDS/RESET: J4.3 (PIN), U7.11 (RESET)
/DDS/SCLK: J4.2 (PIN), U7.14 (SCLK)
/DDS/SDATA: J4.4 (PIN), U7.13 (SDATA)
/DDS/SIGNBITOUT: J2.1 (In), U7.16 (SIGNBITOUT)
/DDS/SLEEP: J4.6 (PIN), U7.12 (SLEEP)
/FB: R6.2, R9.1, U4.7 (FB)
/LX: C12.1, L1.1, U4.11 (LX)
/Output_Stage/ELLIP-IN: C20.1, C24.1, K1.12, L2.1
/Output_Stage/ELLIP-OUT: C23.2, C28.1, K2.12, L5.2, R12.1
/Output_Stage/FILT-EN: J4.10 (PIN), U5.3 (EN)
/Output_Stage/FILT-OUT: K2.7, TP11.1, U6.3 (+IN)
/Output_Stage/FILT-SWITCH: J4.9 (PIN), U5.2 (VIN)
/Output_Stage/FILTER-SW-IN: C17.2, K1.1, TP7.1
/Output_Stage/FILTER-SW-OUT: C18.2, K2.1, TP9.1
/Output_Stage/LIN-PHASE-IN: C30.1, K1.10, L6.1
/Output_Stage/LIN-PHASE-OUT: C33.1, K2.10, L8.2, R15.1
/Output_Stage/OUT: J5.1 (In), R13.2, R14.2
/PG: R1.2, U2.7 (PG)
/RESET: R7.2, U4.3 (RESET)
/RT/SYNC: R8.1, U4.6 (RT/SYNC)
/SS: C13.1, U4.4 (SS)
/VCC: C14.1, U4.5 (VCC)
/VIN: C1.1, C2.1, C6.1, C7.1, J1.1, R2.1, R4.2, R7.1, U2.8 (VIN), U4.1 (IN)
GND: C1.2, C2.2, C3.2, C4.2, C5.2, C6.2, C7.2, C8.2, C9.2, C10.2, C11.2, C15.2, C16.1, C19.2, C24.2, C25.2, C26.2, C27.2, C28.2, C29.2, C30.2, C31.2, C32.2, C33.2, C34.2, C35.1, C36.1, C37.2, C40.1, C41.2, C42.1, C43.2, C44.2, C45.1, C46.1, C47.2, C48.2, C49.1, C50.1, D2.2 (A), J1.2, J2.2 (GND), J3.2 (GND), J4.1 (PIN), J5.2 (GND), K1.6, K2.6, L1.2, POT1.2, R3.2, R5.1, R6.1, R10.1, R12.2, R15.2, R21.2, R22.2, R25.2, TP3.1, TP6.1, TP12.1, TP13.1, TP14.1, TP15.1, TP16.1, TP24.1, TP25.1, TP26.1, TP27.1, TP28.1, TP29.1, U1.2 (GND), U2.3 (GND), U2.6 (GND), U3.1 (GND), U4.9 (GND), U5.4 (GND), U5.5 (GND), U7.7 (DGND), U7.18 (AGND), X1.2 (GND)
unnamed: C17.1, C18.1, D1.2 (A), D2.1 (K), TP8.1, U5.6 (OUT), U5.7 (OUT)
unnamed: C20.2, C21.1, C25.1, L2.2, L3.1
unnamed: C21.2, C22.1, C26.1, L3.2, L4.1
unnamed: C22.2, C23.1, C27.1, L4.2, L5.1
unnamed: C31.1, L6.2, L7.1
unnamed: C32.1, L7.2, L8.1
unnamed: C38.1, R16.2, R18.1, TP18.1, U8.2 (-IN)
unnamed: C38.2, R16.1, R20.2, U8.6
unnamed: C46.2, R24.1, R25.1, TP23.1, U8.3 (+IN)
unnamed: POT1.1, POT1.3, R17.1
unnamed: Q1.2 (E), R18.2, R19.1
unnamed: Q2.2 (E), R24.2, R26.1
unnamed: R10.2, R11.1, U6.4 (-IN)
unnamed: R11.2, R13.1, R14.1, U6.1
unnamed: R23.2, X1.3 (OUT)
VDD-MCLK: FB1.2, TP21.1, X1.4 (VDD)

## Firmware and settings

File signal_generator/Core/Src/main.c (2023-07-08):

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
/* Includes ------------------------------------------------------------------*/
#include "main.h"

/* USER CODE BEGIN Includes */
#include "AD9834.h"
/* USER CODE END Includes */

SPI_HandleTypeDef hspi1;

/* USER CODE BEGIN PV */
AD9834_Connection ad9834_connection;
/* USER CODE END PV */

void SystemClock_Config(void);
static void MX_GPIO_Init(void);
static void MX_SPI1_Init(void);
/* USER CODE BEGIN PFP */
void enable_elliptic_filter();
void enable_linear_phase_filter();
void enable_filter_switch();
void disable_filter_switch();
/* USER CODE END PFP */

/**
  * @brief  The application entry point.
  * @retval int
  */
int main(void)
{
  /* MCU Configuration--------------------------------------------------------*/

  /* Reset of all peripherals, Initializes the Flash interface and the Systick. */
  HAL_Init();

  /* Configure the system clock */
  SystemClock_Config();

  /* Initialize all configured peripherals */
  MX_GPIO_Init();
  MX_SPI1_Init();
  /* USER CODE BEGIN 2 */

  ad9834_connection.hspi = &hspi1;
  ad9834_connection.fsync_gpio = GPIOA;
  ad9834_connection.sleep_gpio = GPIOB;
  ad9834_connection.reset_gpio = GPIOA;
  ad9834_connection.phase_select_gpio = GPIOA;
  ad9834_connection.freq_select_gpio = GPIOB;
  ad9834_connection.fsync_pin = FSYNC_Pin;
  ad9834_connection.sleep_pin = SLEEP_Pin;
  ad9834_connection.reset_pin = RESET_Pin;
  ad9834_connection.phase_select_pin = PHASE_SLCT_Pin;
  ad9834_connection.freq_select_pin = FREQ_SLCT_Pin;

  AD9834_init(&ad9834_connection);

  // --------------------------------------------------
  // ------- Max Frequency Sine wave Test START -------
  // --------------------------------------------------

  AD9834_set_frequency(&ad9834_connection, 17000000, 0);
  AD9834_set_phase(&ad9834_connection, 0, 0);
  enable_filter_switch();
  enable_elliptic_filter();
  AD9834_set_sinusoidal_output(&ad9834_connection);
  AD9834_reset_pin_disable(&ad9834_connection);

  // ------- Max Frequency Sine wave Test END -------

  // -------------------------------------------------
  // -------- Triangle Wave Output Test START --------
  // -------------------------------------------------

//  AD9834_set_frequency(&ad9834_connection, 3600000, 0);
//  AD9834_set_phase(&ad9834_connection, 0, 0);
//  enable_filter_switch();
//  enable_linear_phase_filter();
//  AD9834_set_triangle_output(&ad9834_connection);
//  AD9834_reset_pin_disable(&ad9834_connection);

  // -------- Triangle Wave Output Test END --------

  // -----------------------------------------------
  // -------- Square Wave Output Test START --------
  // -------------------------------------------------

//    AD9834_set_frequency(&ad9834_connection, 300000, 0);
//    AD9834_set_phase(&ad9834_connection, 0, 0);
//    enable_filter_switch();
//    enable_elliptic_filter();
//    AD9834_set_square_output(&ad9834_connection);
//    AD9834_reset_pin_disable(&ad9834_connection);

  // -------- Square Wave Output Test END --------

  // -----------------------------------------------
  // -------- Frequency Register Test START --------
  // ------------------------------------------------

//    AD9834_set_frequency(&ad9834_connection, 1000, 0);
//    AD9834_set_frequency(&ad9834_connection, 300, 1);
//    AD9834_set_phase(&ad9834_connection, 0, 0);
//    enable_filter_switch();
//    enable_elliptic_filter();
//    AD9834_set_sinusoidal_output(&ad9834_connection);
//    AD9834_reset_pin_disable(&ad9834_connection);

  // -------- Frequency Register Test END --------

  // -------------------------------------------
  // -------- Phase Register Test START --------
  // -------------------------------------------

//  AD9834_set_frequency(&ad9834_connection, 1000, 0);
//  AD9834_set_phase(&ad9834_connection, 0, 0);
//  AD9834_set_phase(&ad9834_connection, 180, 1);
//  enable_filter_switch();
//  enable_elliptic_filter();
//  AD9834_set_sinusoidal_output(&ad9834_connection);
//  AD9834_reset_pin_disable(&ad9834_connection);

  // -------- Phase Register Test END --------

  // -------------------------------------------
  // -------- Power Supply Test START ----------
  // -------------------------------------------

//  AD9834_set_frequency(&ad9834_connection, 1000000, 0);
//  AD9834_set_phase(&ad9834_connection, 0, 0);
//  enable_filter_switch();
//  enable_elliptic_filter();
//  AD9834_set_sinusoidal_output(&ad9834_connection);
//  AD9834_reset_pin_disable(&ad9834_connection);

  // -------- Power Supply Test END ----------

  /* USER CODE END 2 */

  /* Infinite loop */
  /* USER CODE BEGIN WHILE */
  while (1)
  {
	  // --------------------------------------------------
	  // ------- Max Frequency Sine wave Test START -------
	  // --------------------------------------------------


	  // ------- Max Frequency Sine wave Test END -------

	  // -------------------------------------------------
	  // -------- Triangle Wave Output Test START --------
	  // -------------------------------------------------

//	  HAL_Delay(8000);
//	  enable_elliptic_filter();
//	  HAL_Delay(8000);
//	  enable_linear_phase_filter();

	  // -------- Triangle Wave Output Test START --------

	  // -----------------------------------------------
	  // -------- Square Wave Output Test START --------
	  // -----------------------------------------------


	  // -------- Square Wave Output Test END --------

	  // -----------------------------------------------
	  // -------- Frequency Register Test START --------
	  // -----------------------------------------------

//	  HAL_Delay(10);
//	  AD9834_frequency_register0_pin(&ad9834_connection);
//	  HAL_Delay(10);
//	  AD9834_frequency_register1_pin(&ad9834_connection);

	  // -------- Frequency Register Test END --------

	  // -------------------------------------------
	  // -------- Phase Register Test START --------
	  // -------------------------------------------

//	  HAL_Delay(3);
//	  AD9834_phase_register0_pin(&ad9834_connection);
//	  HAL_Delay(3);
//	  AD9834_phase_register1_pin(&ad9834_connection);

	  // -------- Phase Register Test END --------

	  // -------------------------------------------
	  // -------- Power Supply Test START ----------
	  // -------------------------------------------


	  // -------- Power Supply Test END ----------

    /* USER CODE END WHILE */

    /* USER CODE BEGIN 3 */
  }
  /* USER CODE END 3 */
}

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
/* USER CODE BEGIN 4 */
void enable_elliptic_filter() {
	HAL_GPIO_WritePin(FILT_SW_GPIO_Port, FILT_SW_Pin, GPIO_PIN_SET);
}

void enable_linear_phase_filter() {
	HAL_GPIO_WritePin(FILT_SW_GPIO_Port, FILT_SW_Pin, GPIO_PIN_RESET);
}

void enable_filter_switch() {
	HAL_GPIO_WritePin(FILT_SW_EN_GPIO_Port, FILT_SW_EN_Pin, GPIO_PIN_SET);
}

void disable_filter_switch() {
	HAL_GPIO_WritePin(FILT_SW_EN_GPIO_Port, FILT_SW_EN_Pin, GPIO_PIN_RESET);
}
/* USER CODE END 4 */
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


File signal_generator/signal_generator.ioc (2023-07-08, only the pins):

Mcu.UserName=STM32L475VGTx
PA5.Signal=SPI1_SCK
PB2.Signal=GPIO_Output
PB1.GPIO_Label=SLEEP
PD14.GPIO_Label=FILT_SW_EN
PA2.Signal=GPIO_Output
PD14.Signal=GPIO_Output
PA4.Signal=GPIO_Output
PB1.Signal=GPIO_Output
PA2.GPIO_Label=RESET
PB2.GPIO_Label=FREQ_SLCT
PA4.GPIO_Label=FSYNC
PA3.GPIO_Label=FILT_SW
PA3.Signal=GPIO_Output
PA7.Signal=SPI1_MOSI

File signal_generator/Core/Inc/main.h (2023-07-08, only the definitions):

#define RESET_Pin GPIO_PIN_2
#define RESET_GPIO_Port GPIOA
#define FILT_SW_Pin GPIO_PIN_3
#define FILT_SW_GPIO_Port GPIOA
#define FSYNC_Pin GPIO_PIN_4
#define FSYNC_GPIO_Port GPIOA
#define SLEEP_Pin GPIO_PIN_1
#define SLEEP_GPIO_Port GPIOB
#define FREQ_SLCT_Pin GPIO_PIN_2
#define FREQ_SLCT_GPIO_Port GPIOB
#define FILT_SW_EN_Pin GPIO_PIN_14
#define FILT_SW_EN_GPIO_Port GPIOD
#define PHASE_SLCT_Pin GPIO_PIN_15
#define PHASE_SLCT_GPIO_Port GPIOA

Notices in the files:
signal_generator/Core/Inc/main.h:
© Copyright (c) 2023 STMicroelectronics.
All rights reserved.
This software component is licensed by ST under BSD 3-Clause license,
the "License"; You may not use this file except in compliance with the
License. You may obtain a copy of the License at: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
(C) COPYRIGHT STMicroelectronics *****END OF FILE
